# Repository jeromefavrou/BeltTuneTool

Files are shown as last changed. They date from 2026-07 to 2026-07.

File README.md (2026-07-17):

# BeltTuneTool

> Outil portable de mesure de la tension des courroies par analyse fréquentielle, basé sur un ESP32, un microphone et un écran TFT.

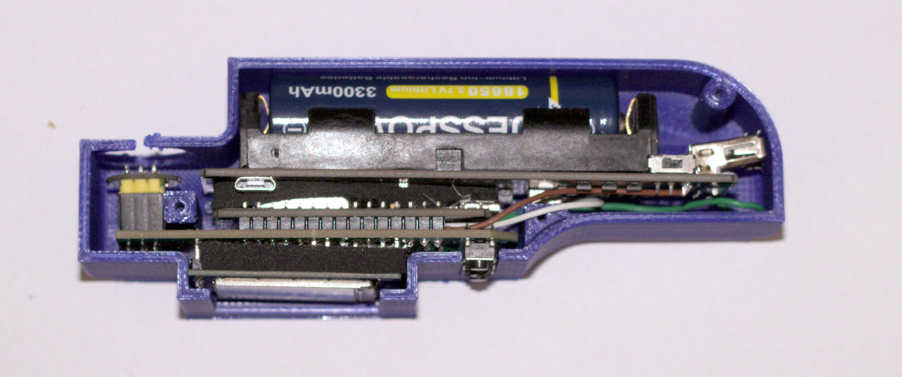
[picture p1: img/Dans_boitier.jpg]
Montage


---

# Sommaire

- [Présentation](#présentation)
- [Principe de fonctionnement](#principe-de-fonctionnement)
- [Matériel](#matériel)
- [Assemblage](#assemblage)
- [Câblage](#câblage)
- [Boîtier](#boîtier)
- [Compilation](#compilation)
- [Utilisation](#utilisation)
- [Menus](#menus)
- [Réglages](#réglages)
- [Mesure d'une courroie](#mesure-dune-courroie)
- [Fichiers Hardware](#fichiers-hardware)
- [Licence](#licence)

---

# Présentation

**BeltTuneTool** est un appareil portable permettant de mesurer la fréquence propre d'une courroie à l'aide d'un microphone et d'une FFT.

À partir de cette fréquence, il devient possible de régler précisément la tension d'une courroie en utilisant la relation :

\[
T = 4 \times \mu \times L^2 \times f^2
\]

avec :

- **T** : tension de la courroie (N)
- **μ** : masse linéique (kg/m)
- **L** : longueur libre (m)
- **f** : fréquence mesurée (Hz)

L'appareil est particulièrement adapté aux :

- imprimantes 3D
- CNC
- machines-outils
- robots
- transmissions par courroie

---

# Principe de fonctionnement

L'utilisateur pince la courroie.

Le microphone enregistre le son.

Une FFT est calculée par l'ESP32 afin d'identifier la fréquence fondamentale.

La fréquence détectée est ensuite utilisée pour calculer automatiquement la tension de la courroie.

---

# Matériel

Pour réaliser un BeltTuneTool, les composants suivants sont nécessaires.

## Électronique

| Quantité | Désignation |
|---:|---|
| 1 | ESP32 DEV |
| 1 | NMP441 Module de Microphone Omnidirectionnel, Microphone à Interface I2S Sortie MEMS  |
| 1 | Module d'affichage TFT IPS 1,3" 240×240 pixels, contrôleur **ST7789**, interface SPI, alimentation 3,3 V |
| 1 | Support de batterie **AZDelivery 18650** avec chargeur intégré (Micro-USB, sortie 5 V / 3 V) |
| 1 | Accumulateur Li-Ion **18650** |
| 3 | Boutons poussoirs **KEY-TH_4P-L6.0-W6.0-P4.50-LS6.5** |
| 2 | Résistances **100 kΩ** |
| 3 | Condensateurs céramique **100 nF** au format **0805** |
| 2 | Barrettes femelles **HDR-F-2.54**, 15 broches |
| 2 | Barrettes femelles **HDR-F-2.54**, 3 broches |
| 1 | Barrette femelle **HDR-F-2.54**, 8 broches |
| 1 | Mousse auto adhesive a mettre entre les carte |

---

## Circuit imprimé

Le PCB personnalisé est fourni dans le dossier :

```
Hardware/
```

Vous y trouverez :

- le schéma électronique ;
- les fichiers Gerber ;
- les fichiers de perçage.

Il suffit de faire fabriquer le PCB auprès du fabricant de votre choix.

---

## Pièces imprimées en 3D

Les trois pièces du boîtier sont disponibles dans le dossier :

```
3D Models/
```

Les formats suivants sont fournis :

- STL
- STEP
- GCode

Les trois pièces à imprimer sont :

- Face avant
- Corps du boîtier
- Couvercle arrière

Une fois imprimées, elles permettent de monter l'ensemble de l'électronique sans modification.

---

## Ensemble des pièces

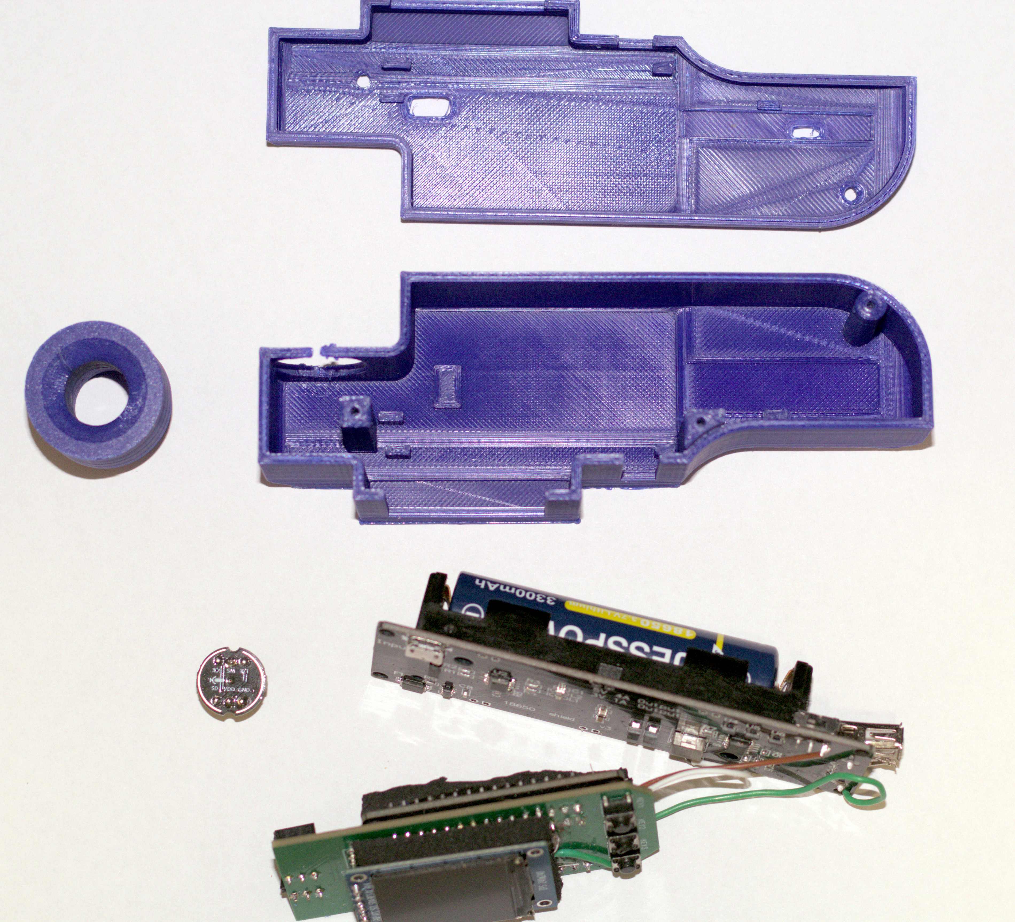
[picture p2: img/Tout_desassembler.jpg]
Pièces


Le boîtier est composé de plusieurs éléments imprimés en 3D accueillant :

- la carte ESP32
- le PCB
- l'écran TFT
- les boutons
- le microphone

---

# Câblage

## Connexions

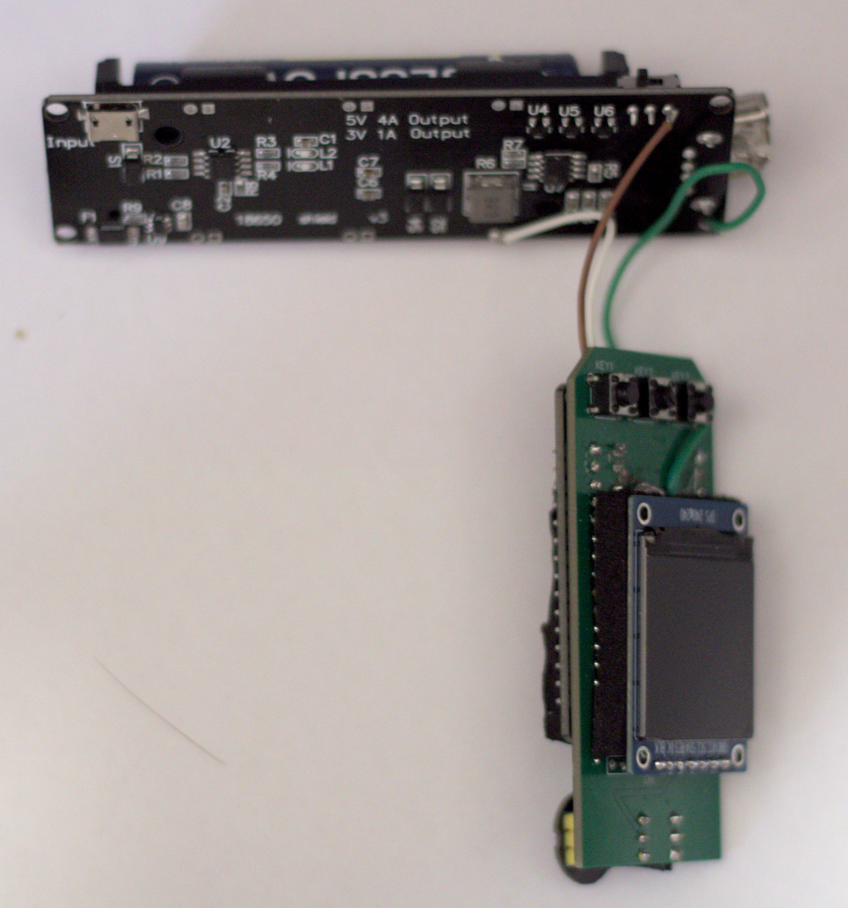
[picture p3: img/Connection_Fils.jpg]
Câblage


Le câblage est volontairement simple afin de limiter les parasites sur le microphone.

Le schéma électronique complet est disponible dans le dossier :

```
Hardware/
```

---

# Boîtier

Une fois assemblé :

Boîtier

Les fichiers suivants sont fournis :

- STEP
- STL
- GCode

Ils sont disponibles dans :

```
3D Models/
```

---

# Compilation

Le projet est développé sous Arduino IDE.

## Bibliothèques nécessaires

Selon votre installation :

- TFT_eSPI
- arduinoFFT

Sélectionner une carte ESP32 compatible puis compiler le projet.
- TFT_eSPI doit etre configuré dans "User_Setup.h"
- ArduinoFFT doit etre dans ca version générique
- des version deja compatible sont disponible dans /BeltTune/Lib
---

# Utilisation

Au démarrage, l'écran principal apparaît.

L'utilisateur :

1. choisit un preset ou règle les paramètres
2. pince la courroie
3. attend la détection
4. lit la fréquence
5. lit la tension calculée

---

# Menus

## Écran principal

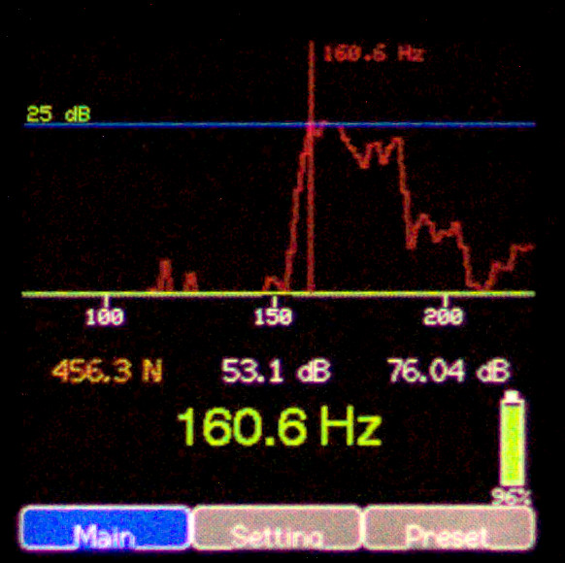
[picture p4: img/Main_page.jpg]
Main


Cet écran affiche :

- fréquence détectée
- tension calculée
- Score en dB
- ecart type des 3 derniere mesure en dB

C'est l'écran utilisé pendant les mesures.

---

## Début d'acquisition

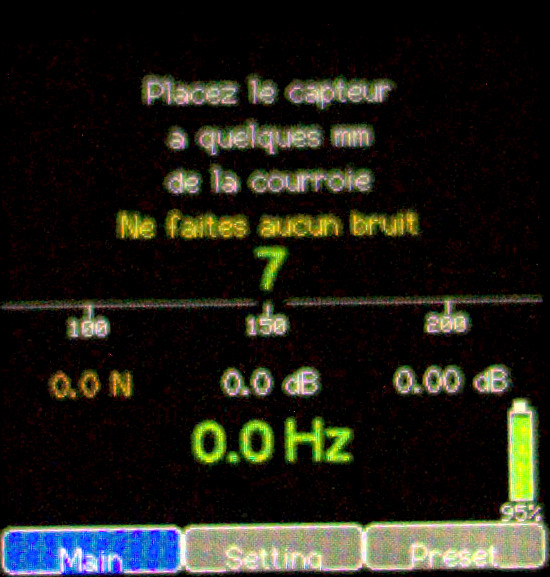
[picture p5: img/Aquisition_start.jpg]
Start


L'appareil quelque seconde avant de commencer l'apprentissage du bruit de fond

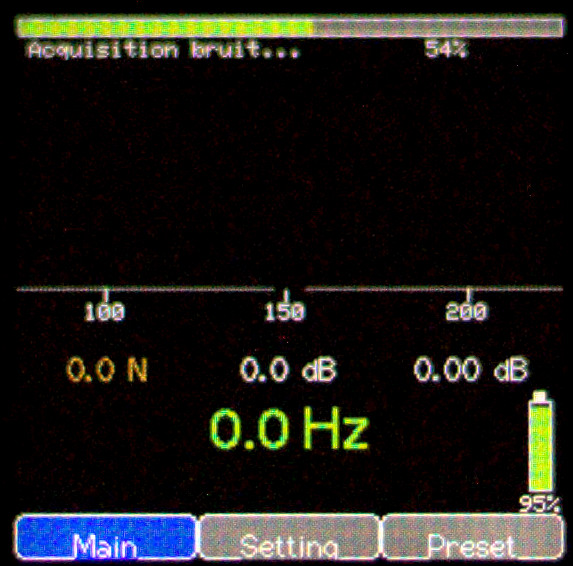
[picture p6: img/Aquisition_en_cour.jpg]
Acquisition


Evité les bruit qui ne sont lier a l'environement.

Ne pas parler , evité les radio-musique

De préférence resté proche de la courroie ( quelque mm )

---

## Menu Settings

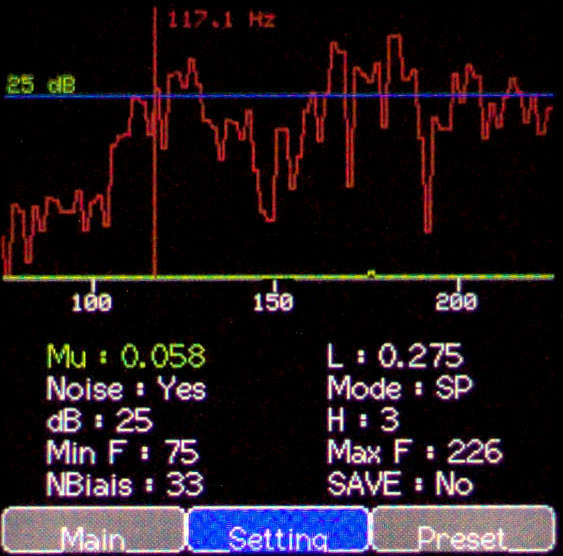
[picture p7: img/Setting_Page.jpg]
Settings


Ce menu permet de modifier tous les paramètres de fonctionnement.

---

## Menu Presets

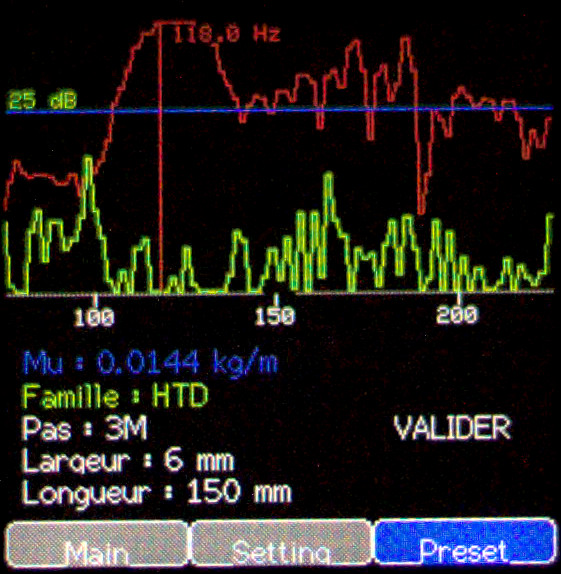
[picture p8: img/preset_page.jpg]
Preset


Les presets permettent de mémoriser rapidement plusieurs configurations de courroies.

Par exemple :

- GT2 6 mm
- GT2 9 mm
- HTD 15 mm
- ...

Le changement de preset recharge apres validation les paramètres associés.

---

# Réglages

## Mu

Masse linéique de la courroie.

Exprimée en kg/m.

Cette valeur est utilisée pour calculer la tension.

Plus elle est précise, plus la tension calculée sera exacte.

Des valeurs prédéfinit dans les pré-set sont définit , néamoins le mieux reste de peser la courroie et de ramené sont poid au metre

---

## L

Longueur libre de la courroie.

Distance entre les deux points fixes.

Elle intervient directement dans le calcul de la tension.

---

## Noise

Lance une mesure du bruit ambiant.

Le niveau mesuré est utilisé afin d'améliorer la détection de la vibration réelle de la courroie.

Cette fonction est particulièrement utile dans un atelier bruyant.

---

## Mode

Choix du mode d'affichage.

---

## dB

Seuil de déclenchement.

Si le signal est inférieur à cette valeur :

- aucune acquisition

Si le signal dépasse cette valeur :

- lancement automatique de la mesure.

---

## H

Nombre d'harmoniques analysées.

Une valeur plus élevée peut améliorer la robustesse de la détection sur certaines courroies.

---

## Min F

Fréquence minimale recherchée.

Permet d'éviter la détection de parasites basse fréquence.

---

## Max F

Fréquence maximale recherchée.

Limite la recherche de la FFT afin d'accélérer les calculs et réduire les faux positifs.

---

## NBiais

Nombre d'échantillons utilisés pour l'estimation du bruit.

Une valeur élevée améliore généralement la stabilité au prix d'un temps d'initialisation plus long.

---

## SAVE

Sauvegarde tous les paramètres dans la mémoire non volatile.

Ils seront automatiquement restaurés au prochain démarrage.

---

# Mesure d'une courroie

## Préparation

Pour obtenir une mesure fiable, il est indispensable que les paramètres correspondent à la courroie mesurée.

Les deux paramètres les plus importants sont :

- **μ (Mu)** : masse linéique de la courroie (kg/m)
- **L** : longueur libre entre les deux points de fixation (m)

> **Important**
>
> La fréquence mesurée est indépendante de ces paramètres, mais **la tension calculée ne sera correcte que si les valeurs de μ et L sont exactes**.

Si ces valeurs sont erronées, la fréquence affichée restera correcte, mais la tension calculée sera fausse.

---

## Déterminer la masse linéique (μ)

La masse linéique peut être obtenue :

- à partir de la documentation du fabricant ;
- ou en la mesurant directement.

Pour cela :

1. courroie de longueur connue ;
2. le peser avec une balance précise ;
3. calculer :

```
μ = Masse / Longueur
```

Exemple :

- longueur : 1 m
- masse : 0,038 kg

```
μ = 0,038 kg/m
```

Cette méthode permet souvent d'obtenir une meilleure précision lorsque la documentation constructeur n'est pas disponible.

---

## Réaliser une mesure

1. Charger un preset ou régler les paramètres.
2. Vérifier **μ** et **L**.
3. Effectuer une acquisition de bruit si nécessaire.
4. Placer le microphone à quelques millimètres de la courroie.
5. Pincer la courroie.
6. Attendre la fin de l'acquisition.
7. Lire la fréquence détectée.
8. Lire la tension calculée.
9. Répété 3 fois et validé avec un ecart type faible

---

# Acquisition du bruit

L'acquisition du bruit permet au BeltTuneTool de mesurer le niveau sonore ambiant afin d'améliorer la détection de la vibration de la courroie.

Pour obtenir un résultat optimal :

- approcher le microphone à seulement quelques millimètres de la courroie ;
- laisser la courroie parfaitement immobile ;
- **éteindre tous les moteurs**, ventilateurs, broches et autres sources de vibrations ;
- éviter toute manipulation pendant l'acquisition.

Plus le bruit de référence est représentatif de l'environnement réel, plus la détection sera robuste.

---

# Comprendre le graphe FFT

Après chaque mesure, le BeltTuneTool analyse le signal sonore grâce à une FFT (Fast Fourier Transform).

Le graphe représente :

- l'axe horizontal : la fréquence (Hz)
- l'axe vertical : l'amplitude du signal

Chaque pic correspond à une composante fréquentielle présente dans la vibration de la courroie.

La fréquence recherchée est la **fréquence fondamentale**, c'est-à-dire la première fréquence de vibration de la courroie.

Les autres pics sont appelés **harmoniques**.

Par exemple :

```
Amplitude

│
│                  ▲ Harmonique 3
│
│          ▲ Harmonique 2
│
│   ▲ Fondamentale
│
└──────────────────────────────────
    50      100      150      Hz
```

Dans un cas idéal, la fondamentale est le pic le plus élevé.

Cependant, selon :

- le matériau de la courroie ;
- sa largeur ;
- sa tension ;
- la position où elle est pincée ;
- la position du microphone ;

certaines harmoniques peuvent devenir plus importantes que la fondamentale.

Le BeltTuneTool utilise donc plusieurs paramètres afin d'identifier automatiquement la bonne fréquence.

---

# Mesures à basse fréquence

La mesure des basses fréquences est plus délicate.

Sous **60 Hz**, même si une calibration spécifique est appliquée, il est fréquent que :

- la fondamentale soit moins énergétique que la deuxième ou troisième harmonique ;
- certaines résonances mécaniques deviennent plus importantes que la vibration principale.

L'algorithme tente de retrouver automatiquement la fondamentale en analysant les relations entre les différents pics, mais cette situation reste physiquement plus difficile.

---

# Limites du capteur

Le microphone MEMS possède naturellement une sensibilité réduite dans les très basses fréquences.

En pratique :

- **au-dessus de 60 Hz** : fonctionnement optimal ;
- **entre 30 et 60 Hz** : les mesures restent possibles mais demandent davantage de précautions ;
- **en dessous de 30 Hz** : les performances du capteur deviennent limitées et la détection peut être moins fiable.

Pour les très faibles fréquences, il est recommandé :

- de placer le microphone très près de la courroie ;
- d'éliminer toute source de vibration parasite ;
- de réaliser plusieurs mesures afin de vérifier leur cohérence.

---

# Conseils pour une mesure fiable

- Utiliser la bonne masse linéique (**μ**).
- Mesurer précisément la longueur libre (**L**).
- Réaliser une acquisition du bruit avant les premières mesures.
- Positionner le microphone à quelques millimètres de la courroie.
- Pincer toujours la courroie de manière similaire.
- Éviter de toucher la machine pendant la mesure.
- Couper les moteurs et les ventilateurs lorsque cela est possible.
- Réaliser plusieurs acquisitions et comparer les résultats.
---

# Fichiers Hardware

Le dossier **Hardware** contient :

- schéma électronique
- PCB
- Gerbers

Le dossier **3D Models** contient :

- fichiers STL
- fichier STEP
- GCode

permettant de reconstruire entièrement l'appareil.

---

# Arborescence

```
BeltTuneTool
│
├── BeltTuneTool/        Code source Arduino + Lib
├── Hardware/            PCB + schéma
├── 3D Models/           STL / STEP / GCode
├── img/                 Documentation
└── README.md
```

---

# Licence

Ce projet est distribué sous licence **MIT**.

Voir le fichier `LICENSE`.

---

# Auteur

Développé par **Jérôme Favrou**.

Contributions, améliorations et retours d'expérience sont les bienvenus.

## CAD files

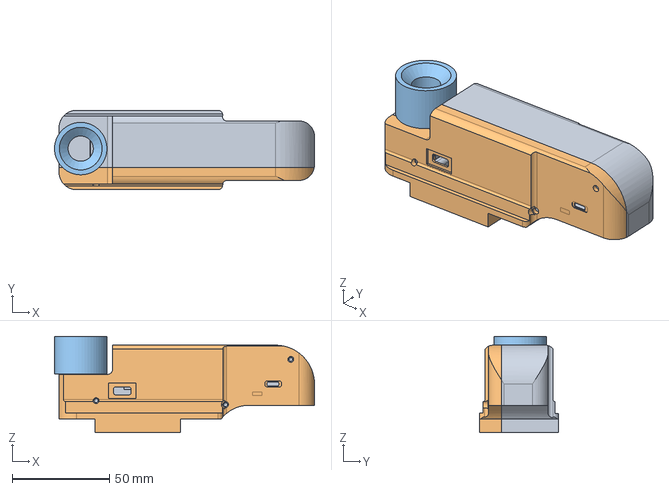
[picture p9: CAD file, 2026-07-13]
3D Models/Coque.step
133.9 x 40.9 x 49.5 mm

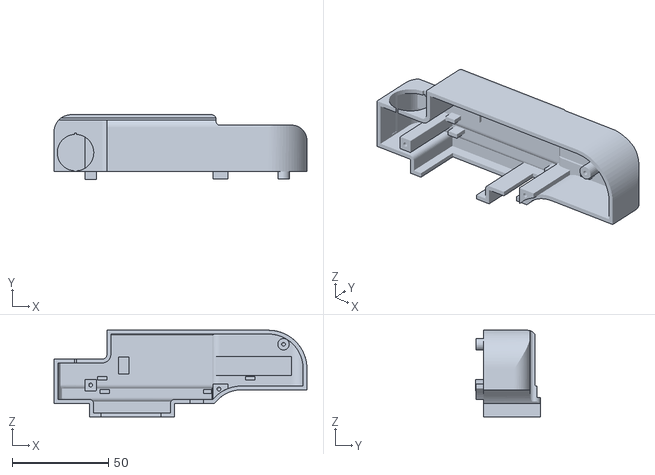
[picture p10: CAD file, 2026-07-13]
3D Models/Coque1.stl
131.6 x 33.7 x 45.0

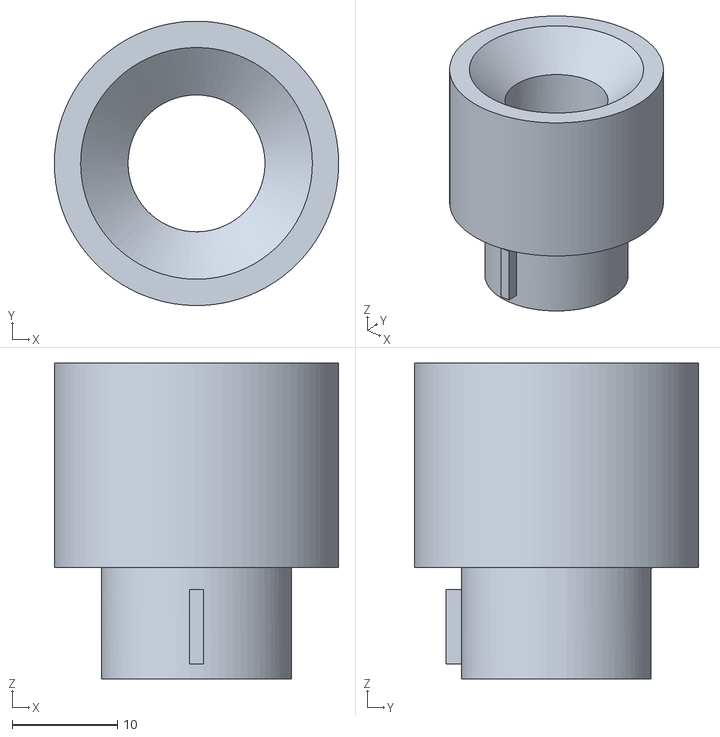
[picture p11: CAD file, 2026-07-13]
3D Models/Tube.stl
27.0 x 27.0 x 30.0

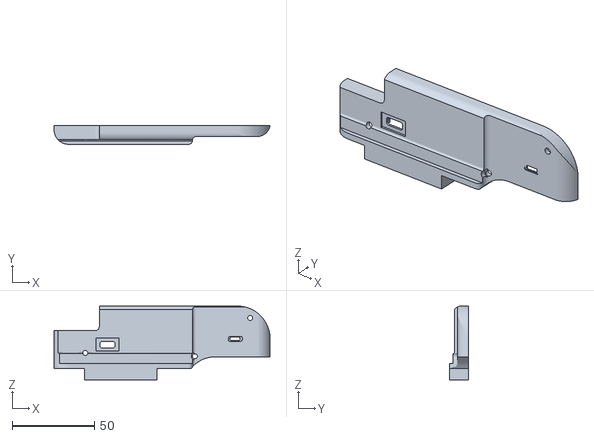
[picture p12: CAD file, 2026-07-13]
3D Models/Coque2.stl
131.5 x 11.4 x 45.0

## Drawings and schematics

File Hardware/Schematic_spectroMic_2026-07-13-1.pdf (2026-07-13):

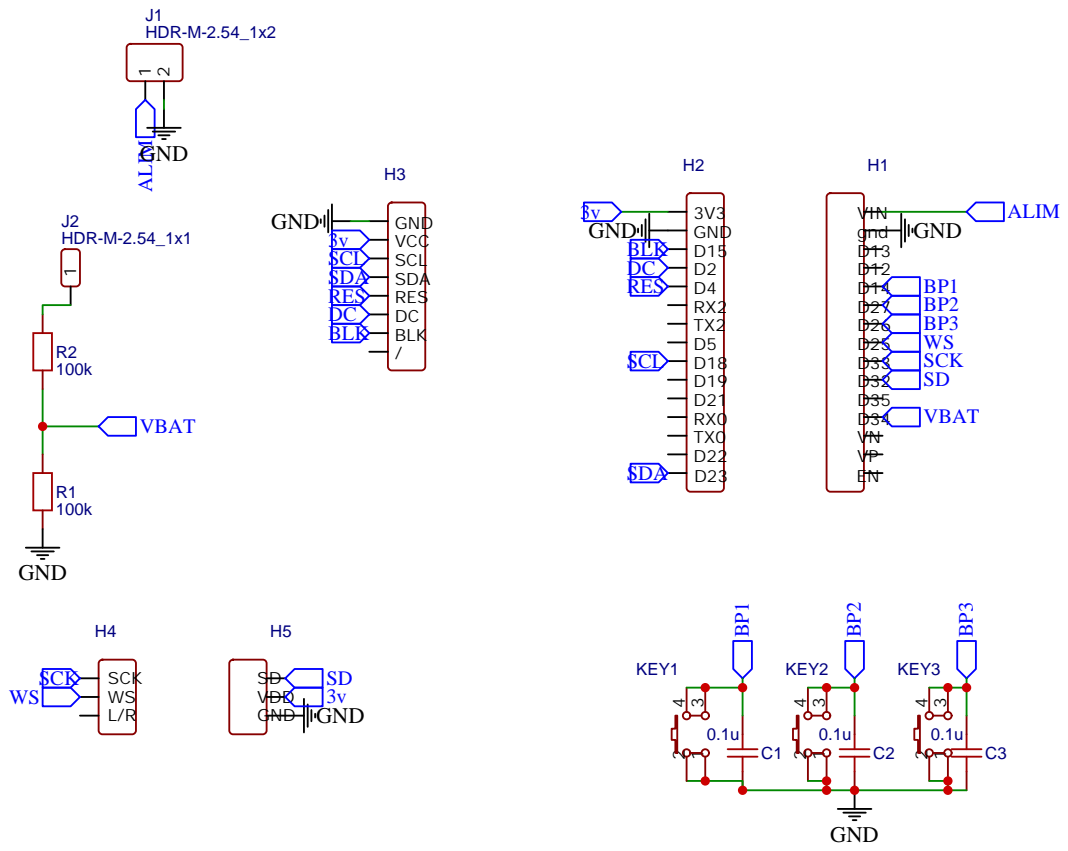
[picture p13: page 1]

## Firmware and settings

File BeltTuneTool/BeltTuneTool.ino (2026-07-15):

/*MIT License

Copyright (c) 2026 Favrou jérôme

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
THE SOFTWARE IS PROVIDED "AS IS", WITHOUT WARRANTY OF ANY KIND, EXPRESS OR
IMPLIED, INCLUDING BUT NOT LIMITED TO THE WARRANTIES OF MERCHANTABILITY,
FITNESS FOR A PARTICULAR PURPOSE AND NONINFRINGEMENT. IN NO EVENT SHALL THE
AUTHORS OR COPYRIGHT HOLDERS BE LIABLE FOR ANY CLAIM, DAMAGES OR OTHER
LIABILITY, WHETHER IN AN ACTION OF CONTRACT, TORT OR OTHERWISE, ARISING FROM,
OUT OF OR IN CONNECTION WITH THE SOFTWARE OR THE USE OR OTHER DEALINGS IN THE
SOFTWARE.*/

#include "headers/DI.hpp"
#include "headers/PanelHerited.hpp"

// Parametres centralises de l'application.
namespace AppConfig
{
constexpr uint8_t kMenuMainIndex = 0;
constexpr uint8_t kMenuSettingIndex = 1;
constexpr uint8_t kMenuPresetIndex = 2;

constexpr uint8_t kButtonSelectPin = 26;
constexpr uint8_t kButtonBackwardPin = 27;
constexpr uint8_t kButtonForwardPin = 14;
constexpr uint8_t kBatteryAdcPin = 34;

constexpr uint16_t kScreenWidth = 240;
constexpr uint16_t kScreenHeight = 240;
constexpr uint16_t kHeaderHeight = 142;
constexpr uint16_t kTabHeight = 20;
constexpr uint16_t kPanelHeight = kScreenHeight - kHeaderHeight - kTabHeight;
constexpr uint16_t kMenuHeight = kScreenHeight - kHeaderHeight;
constexpr uint16_t kTopInfoHeight = 120;

constexpr uint32_t kInputPollDelayMs = 10;
constexpr uint32_t kLongPressDelayMs = 1000;
constexpr uint32_t kInitialRepeatDelayMs = 300;
constexpr uint32_t kUiRefreshDelayMs = 100;
constexpr uint32_t kStartupScreenDelayMs = 5000;
constexpr uint32_t kUsageScreenDelayMs = 8000;

constexpr float kAdcReferenceVoltage = 3.3f;
constexpr float kAdcMaxValue = 4095.0f;
constexpr float kBatteryDividerRatio = 2.0f;
constexpr float kBatteryCalibrationFactor = 1.08f;
constexpr float kBatteryPercentMinVoltage = 3.2f;
constexpr float kBatteryPercentMaxVoltage = 4.1f;
constexpr float kBatteryCriticalPercent = 10.0f;

constexpr uint64_t kDeepSleepWakeupUs = 3600ULL * 1000000ULL;

constexpr BaseType_t kTaskPriority = 1;
constexpr uint32_t kTaskCore0StackSize = 4096;
constexpr uint32_t kTaskCore1StackSize = 8096;
constexpr uint8_t kTaskCore0Id = 0;
constexpr uint8_t kTaskCore1Id = 1;

constexpr int kCenterX = kScreenWidth / 2;
constexpr int kStartupTitleY = 20;
constexpr int kStartupVersionY = 50;
constexpr int kStartupCopyrightY = 80;
constexpr int kStartupLicenseY = 110;
constexpr int kStartupRepoY = 140;

constexpr int kUsageSelectShortY = 10;
constexpr int kUsageSelectLongY = 30;
constexpr int kUsageAdjustY = 50;
constexpr int kUsageAdjustFastY = 70;

constexpr int kButtonLegendY = 220;
constexpr int kButtonLegendWidth = 44;
constexpr int kButtonLegendHeight = 18;
constexpr int kButtonLegendRadius = 4;
constexpr int kButtonLegendTextYOffset = 5;
constexpr int kSelectLegendX = 18;
constexpr int kBackwardLegendX = 98;
constexpr int kForwardLegendX = 178;

constexpr int kBiasNoise = 5;

constexpr double kTensionFactor = 4.0;
constexpr uint8_t kSpectrumSelectedValue = 0;

constexpr char kMainMenuName[] = "Main";
constexpr char kTaskCore0Name[] = "Task0";
constexpr char kTaskCore1Name[] = "Task1";

constexpr char kAppTitle[] = "BeltTuneTool";
constexpr char kAppVersion[] = "Version 1.0";
constexpr char kAppCopyright[] = "2026 - Jerome Favrou";
constexpr char kAppRepository[] = "github.com/jeromefavrou/BeltTuneTool";
constexpr char kAppLicense[] = "Licence : MIT";

constexpr char kUsageSelectShort[] = "SEL court : changer d'onglet";
constexpr char kUsageSelectLong[] = "SEL long : entrer/sortir du menu";
constexpr char kUsageAdjust[] = "FW/BW : modifier la valeur";
constexpr char kUsageAdjustFast[] = "FW/BW maintenu : defilement rapide";

constexpr char kSelectLabel[] = "SEL";
constexpr char kBackwardLabel[] = "BWD";
constexpr char kForwardLabel[] = "FWD";
}


// Taches FreeRTOS et ressources partagees entre acquisition et interface.
TaskHandle_t TaskCore0;
TaskHandle_t TaskCore1;

bool lockTft = false;

TFT_eSPI tft = TFT_eSPI();

TFT_MultiCore tftMultiCore(&tft);

std::shared_ptr<Menu> menu;

std::shared_ptr<FFT_detected<double>> FFT;


std::shared_ptr<MainPanel> mainPanel;
std::shared_ptr<SettingPanel> settingPanel;
std::shared_ptr<PresetPanel> presetPanel;

// Etat runtime expose a l'interface principale.
double last_freq = 0;
double seui_db = 25;

double mu = 0.77;      // kg/m
double L  = 0.5;       // m
bool Smode = false;

double tension = 0;
double accel = 0;
uint8_t functSel = 0;
bool selPanel = false;

// Gere les boutons et la navigation dans les panneaux de configuration.
void tacheCore0(void * parameter) 
{
  
  DIAvr bp_sel;
  DIAvr bp_bw;
  DIAvr bp_fw;

  bp_sel.init(AppConfig::kButtonSelectPin, INPUT_PULLUP , DI::Signal::PULL_UP);
  bp_bw.init(AppConfig::kButtonBackwardPin, INPUT_PULLUP, DI::Signal::PULL_UP);
  bp_fw.init(AppConfig::kButtonForwardPin, INPUT_PULLUP , DI::Signal::PULL_UP );

  uint32_t lastRepeatTime = 0;
  uint32_t repeatDelay = AppConfig::kInitialRepeatDelayMs;

  while (true) 
  {
    vTaskDelay(pdMS_TO_TICKS(AppConfig::kInputPollDelayMs));
     bp_sel.read();
     bp_bw.read();
     bp_fw.read();

   
    // Enregistre les reglages si l'utilisateur a demande une sauvegarde.
    settingPanel->saveToEEPROM();
         

      if( bp_sel.n() && !selPanel )
      {
            menu->nextPanel();

            continue;

      } 
      else if( bp_sel.n_fixed() && selPanel )
      {
        // En mode edition, un appui select passe au champ suivant.
          int raw = analogRead(AppConfig::kBatteryAdcPin);

          // Conversion approximative pour ADC 12 bits
          float adcVoltage = raw * AppConfig::kAdcReferenceVoltage / AppConfig::kAdcMaxValue;
           
          // On multiplie par 2 car le pont diviseur divise la tension par 2
          float batteryVoltage = adcVoltage * AppConfig::kBatteryDividerRatio * AppConfig::kBatteryCalibrationFactor; 
          mainPanel->setVbat( batteryVoltage );

          if( menu->getSelect() == 2)
          {
              presetPanel->nextSetting();
              presetPanel->draw();

              presetPanel->apply  =false;

          }
          else if( menu->getSelect() == 1)
          { 
             
            menu->getPanelSelected()->nextSetting();
            menu->getPanelSelected()->draw();
          }

            
          continue;
        
        
      }
      else if( bp_sel.p_fixed_Repeat(AppConfig::kLongPressDelayMs) == 2 && (menu->getSelect() == AppConfig::kMenuSettingIndex || menu->getSelect() == AppConfig::kMenuPresetIndex) )
      {

        // Bascule entre navigation d'onglets et edition du panneau courant.
          selPanel = !selPanel;

          tftMultiCore.lock();
          menu->getPanelSelected()->selPanel = selPanel;
          tftMultiCore.unlock();

          menu->draw();

          bp_fw.clear();
          bp_fw.clear();
          bp_sel.clear();
          
          vTaskDelay(pdMS_TO_TICKS(AppConfig::kLongPressDelayMs));

          continue;
      }

      if( (menu->getSelect() == AppConfig::kMenuSettingIndex || menu->getSelect() == AppConfig::kMenuPresetIndex) && selPanel )
      {

        if( bp_fw.p_fixed_Repeat(repeatDelay) == 1 )
        {
          menu->getPanelSelected()->fwdSetting();
          menu->getPanelSelected()->draw();
        }
        else if( bp_bw.p_fixed_Repeat(repeatDelay) == 1 )
        {
          menu->getPanelSelected()->bwdSetting();
          menu->getPanelSelected()->draw();

        }
        if( bp_fw.p_fixed_Repeat(repeatDelay) == 2 )
        {
          menu->getPanelSelected()->fwdSpeedSetting();
          menu->getPanelSelected()->draw();

        
          vTaskDelay(pdMS_TO_TICKS(repeatDelay/2));

        }
        else if( bp_bw.p_fixed_Repeat(repeatDelay) == 2 )
        {
          menu->getPanelSelected()->bwdSpeedSetting();
          menu->getPanelSelected()->draw();

          vTaskDelay(pdMS_TO_TICKS(repeatDelay/2));

        }

        continue;

      }

  
  }
}

// Gere l'acquisition audio, la FFT et le rendu des donnees detectees.
void tacheCore1(void * parameter)
{
    tftMultiCore.lock();
    settingPanel->setting.LearnNoise = false;
    tftMultiCore.unlock();

    while(true)
    {
        // Apprend le bruit de fond avant de lancer la detection nominale.
        if(!settingPanel->setting.LearnNoise)
        {
            FFT->NoiseAquisition(settingPanel->setting.nNoise , AppConfig::kBiasNoise);

            tftMultiCore.lock();
            settingPanel->setting.LearnNoise = true;
            tftMultiCore.unlock();
        }

        // Traite une nouvelle fenetre FFT quand assez d'echantillons sont prets.
        if(FFT->readSamples())
        {
            FFT->buildFFTBuffer();

            FFT->computeFFT();

            FFT->subNoiseBackground();

            HpsData hpsData =
                FFT->Hps(
                    seui_db,
                    settingPanel->setting.nHarmonics);

            bool lastBest = false;

            if(hpsData.lastMesures[0] >= settingPanel->setting.minHz &&
               hpsData.lastMesures[0] <= settingPanel->setting.maxHz)
            {
                last_freq = hpsData.lastMesures[0];

                lastBest = true;

                double tension =
                    AppConfig::kTensionFactor *
                    settingPanel->setting.mu *
                    settingPanel->setting.L *
                    settingPanel->setting.L *
                    last_freq *
                    last_freq;

                if(menu->getSelect() == AppConfig::kMenuMainIndex)
                {
                    mainPanel->setValues(
                        last_freq,
                        hpsData.score,
                        hpsData.stdDev,
                        tension);

                    mainPanel->draw();
                }
            }

            if(settingPanel->setting.Smode)
                FFT->updateSG();
            else
                FFT->updateSpectrum(
                    settingPanel->setting.seui_db,
                    last_freq,
                    lastBest,
                    functSel == AppConfig::kSpectrumSelectedValue);
        }

              // Rend explicitement la main au scheduler entre deux traitements.
        taskYIELD();
    }
}

          // Affiche l'ecran d'accueil dans la zone haute avant l'initialisation complete.
void drawStartupScreen(TFT_eSPI &tft)
{
    tft.fillScreen(TFT_BLACK);

    tft.setTextColor(TFT_WHITE, TFT_BLACK);
    tft.setTextFont(2);

    tft.drawCentreString(AppConfig::kAppTitle, AppConfig::kCenterX, AppConfig::kStartupTitleY, 2);
    tft.drawCentreString(AppConfig::kAppVersion, AppConfig::kCenterX, AppConfig::kStartupVersionY, 2);
    tft.drawCentreString(AppConfig::kAppCopyright, AppConfig::kCenterX, AppConfig::kStartupCopyrightY, 2);
    tft.drawCentreString(AppConfig::kAppRepository, AppConfig::kCenterX, AppConfig::kStartupRepoY, 1);
    tft.drawCentreString(AppConfig::kAppLicense, AppConfig::kCenterX, AppConfig::kStartupLicenseY, 2);

}

  // Affiche l'aide d'utilisation et le rappel visuel des boutons physiques.
void drawUsageInfo(TFT_eSPI &tft)
{
    tft.fillRect(0, 0, AppConfig::kScreenWidth, AppConfig::kTopInfoHeight, TFT_BLACK);

    tft.setTextColor(TFT_WHITE, TFT_BLACK);

    tft.drawCentreString(AppConfig::kUsageSelectShort, AppConfig::kCenterX, AppConfig::kUsageSelectShortY, 1);
    tft.drawCentreString(AppConfig::kUsageSelectLong, AppConfig::kCenterX, AppConfig::kUsageSelectLongY, 1);
    tft.drawCentreString(AppConfig::kUsageAdjust, AppConfig::kCenterX, AppConfig::kUsageAdjustY, 1);
    tft.drawCentreString(AppConfig::kUsageAdjustFast, AppConfig::kCenterX, AppConfig::kUsageAdjustFastY, 1);

    tft.drawRoundRect(AppConfig::kSelectLegendX, AppConfig::kButtonLegendY, AppConfig::kButtonLegendWidth, AppConfig::kButtonLegendHeight, AppConfig::kButtonLegendRadius, TFT_WHITE);
    tft.drawCentreString(AppConfig::kSelectLabel, AppConfig::kSelectLegendX + AppConfig::kButtonLegendWidth / 2, AppConfig::kButtonLegendY + AppConfig::kButtonLegendTextYOffset, 1);

    tft.drawRoundRect(AppConfig::kBackwardLegendX, AppConfig::kButtonLegendY, AppConfig::kButtonLegendWidth, AppConfig::kButtonLegendHeight, AppConfig::kButtonLegendRadius, TFT_WHITE);
    tft.drawCentreString(AppConfig::kBackwardLabel, AppConfig::kBackwardLegendX + AppConfig::kButtonLegendWidth / 2, AppConfig::kButtonLegendY + AppConfig::kButtonLegendTextYOffset, 1);

    tft.drawRoundRect(AppConfig::kForwardLegendX, AppConfig::kButtonLegendY, AppConfig::kButtonLegendWidth, AppConfig::kButtonLegendHeight, AppConfig::kButtonLegendRadius, TFT_WHITE);
    tft.drawCentreString(AppConfig::kForwardLabel, AppConfig::kForwardLegendX + AppConfig::kButtonLegendWidth / 2, AppConfig::kButtonLegendY + AppConfig::kButtonLegendTextYOffset, 1);
}

  // Efface l'ecran complet avant un nouvel affichage plein ecran.
void clearScreen(TFT_eSPI &tft)
{
    tft.fillRect(0, 0, AppConfig::kScreenWidth, AppConfig::kScreenHeight, TFT_BLACK);
} 


  // Initialise l'ecran, la batterie, les panneaux et les taches FreeRTOS.
void setup()
{
    pinMode(TFT_BL, OUTPUT);
    digitalWrite(TFT_BL, HIGH);

    analogSetPinAttenuation(AppConfig::kBatteryAdcPin, ADC_11db);

     int raw = analogRead(AppConfig::kBatteryAdcPin);

    // Mesure instantanee de la batterie a l'allumage.
    float adcVoltage = raw * AppConfig::kAdcReferenceVoltage / AppConfig::kAdcMaxValue;
     
    // Compensation du pont diviseur et de la calibration ADC.
    float batteryVoltage = adcVoltage * AppConfig::kBatteryDividerRatio * AppConfig::kBatteryCalibrationFactor; 
    


     tft.init();
     tft.setRotation(0);
     tft.fillScreen(TFT_BLACK);    
     
     
    // Conversion de la tension en estimation de pourcentage Li-Ion.
    float batteryPercent = (batteryVoltage - AppConfig::kBatteryPercentMinVoltage) / (AppConfig::kBatteryPercentMaxVoltage - AppConfig::kBatteryPercentMinVoltage) * 100.0f;
    batteryPercent = constrain(batteryPercent, 0.0f, 100.0f);
    
    if (batteryPercent < AppConfig::kBatteryCriticalPercent)
    {
        tft.fillScreen(TFT_BLACK);
        digitalWrite(TFT_BL, LOW);
    
      delay(AppConfig::kUiRefreshDelayMs);
    
      esp_sleep_enable_timer_wakeup(AppConfig::kDeepSleepWakeupUs);
    
        esp_deep_sleep_start();
    }

    // Cree l'instance FFT partagee entre la tache audio et les panneaux.
    FFT = std::shared_ptr<FFT_detected<double>>( new FFT_detected<double>(tftMultiCore,  SAMPLING_FREQUENCY, SAMPLES, I2S_WS, I2S_SD, I2S_SCK)); 

    drawStartupScreen(tft);
    delay(AppConfig::kStartupScreenDelayMs);
    clearScreen(tft);

    drawUsageInfo(tft);
    delay(AppConfig::kUsageScreenDelayMs);
    clearScreen(tft);


    // Instancie le menu et les panneaux utilises par l'interface.
    menu = std::shared_ptr<Menu>(new Menu( AppConfig::kMainMenuName, vect2(0, AppConfig::kHeaderHeight), vect2(AppConfig::kScreenWidth, AppConfig::kMenuHeight)));

     mainPanel = std::shared_ptr<MainPanel>(new MainPanel( tftMultiCore, vect2(0, AppConfig::kHeaderHeight), vect2(AppConfig::kScreenWidth, AppConfig::kPanelHeight)));
    settingPanel = std::shared_ptr<SettingPanel>(new SettingPanel( tftMultiCore, FFT, vect2(0, AppConfig::kHeaderHeight), vect2(AppConfig::kScreenWidth, AppConfig::kPanelHeight)));
     presetPanel = std::shared_ptr<PresetPanel>(new PresetPanel( tftMultiCore, FFT, settingPanel, vect2(0, AppConfig::kHeaderHeight), vect2(AppConfig::kScreenWidth, AppConfig::kPanelHeight)));
    
    
    settingPanel->loadFromEEPROM();
    
    menu->addPanel(mainPanel);
    menu->addPanel(settingPanel);
    menu->addPanel(presetPanel);

    mainPanel->setVbat( batteryVoltage );
    menu->draw();

    delay(AppConfig::kUiRefreshDelayMs);


    FFT->mappingFreq(settingPanel->setting.minHz, settingPanel->setting.maxHz);

    
    // Demarre la navigation utilisateur sur le coeur 0.
    xTaskCreatePinnedToCore(tacheCore0, AppConfig::kTaskCore0Name, AppConfig::kTaskCore0StackSize, NULL, AppConfig::kTaskPriority, &TaskCore0, AppConfig::kTaskCore0Id);

    // Demarre le traitement audio et l'analyse FFT sur le coeur 1.
    xTaskCreatePinnedToCore(tacheCore1, AppConfig::kTaskCore1Name, AppConfig::kTaskCore1StackSize, NULL, AppConfig::kTaskPriority, &TaskCore1, AppConfig::kTaskCore1Id);
}

  // Toute l'application tourne dans les taches FreeRTOS; la loop reste idle.
void loop()
{
    vTaskDelay(portMAX_DELAY);
}

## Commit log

2026-07-15 Update noise acquisition method with bias noise
    [BeltTuneTool.ino]
2026-07-16 Enhance README with electronics and assembly details
    Added detailed electronics and assembly sections to the README.
